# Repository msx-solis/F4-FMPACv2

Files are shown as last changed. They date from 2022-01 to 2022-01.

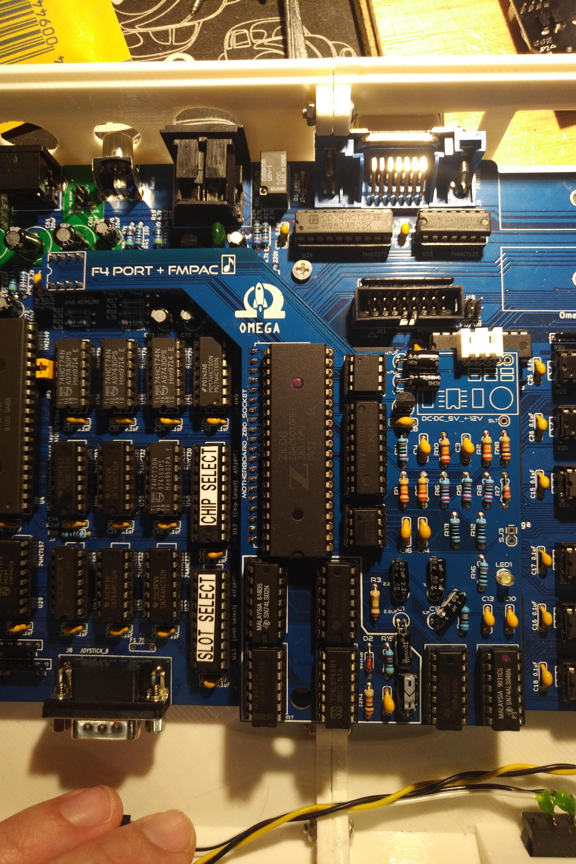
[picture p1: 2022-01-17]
pictures/IMG_20210918_0122434.jpg

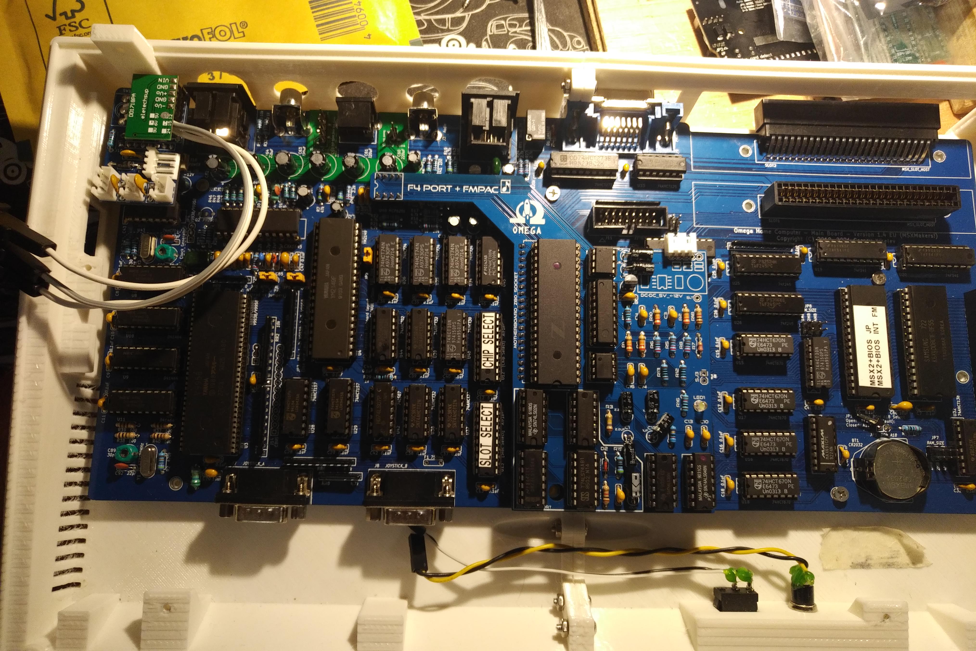
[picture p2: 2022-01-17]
pictures/IMG_20210918_0122565.jpg

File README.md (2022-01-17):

# F4-FMPACv2
Placa de circuito impreso diseñada a partir del proyecto F4-FMPAC del grupo RSBC.
Este circuito permite mejorar las capacidades musicales de los ordenadores MSX, es compatible con los estándares FMPAC y msxmusic.
La versión 2 está especificamente diseñada para adaptarse a las dimensiones del OMEGA HOME COMPUTER, y a diferencia de la versión anterior su diseño evita tener que soldar componentes de superficie (SMD) para facilitar la construcción por parte de los más novatos.
El circuito dispone de dos tiras de pines en la parte inferior para ser insertadas en el zocalo del procesador z80, que debe ser extraido de la placa base original e instalado en el zócalo destinado a tal efecto en esta placa.
Además requiere de ser alimentado a +12v y -12v porque de lo contrario el OMEGA no iniciará adecuadamente.
La alimentación puede ser suministrada mediante un módulo eletechsup DD1718PA de +12/-12v, instalando este en el zócalo previsto para tal proposito, o bien proporcionando dichos voltages en los pines 3-5 de dicho zócalo.
También requiere la reprogramación de la ROM del sistema para incorporar una extensión del BIOS que dé soporte a este circuito, de lo contrario los programas que soportan la extensión seguirán omitiendo el módulo y utilizando el sistema FM principal.
A diferencia de la versión anterior este PCB no incorpora zócalo para memoria ROM ni señales a tomar de un slot de cartucho.
Como instrucciones de montaje se pueden seguir las publicadas para la versión anterior en:
https://msxmakers.design.blog/proyectos/f4-fmpac/

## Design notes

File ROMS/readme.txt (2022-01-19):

Esta carpeta contiene un fichero binario para grabar las ROM del sistema OMEGA con 2 paginas distintas.
Una de las páginas tiene el sistema configurado con la ROM MSX2+ original y la segunda incluye varias modificaciones:
- Configuración regional internacional.
- Símbolo de contrabarra en lugar del yen.
- Soporte para fmpac (en caso de no estar instalado algunos juegos pierden el sonido).
Con este sistema, conectando un interruptor a JP1 de la placa base se puede conmutar entre ambas opciones, la configuración
regional es inmediata, el soporte de FMPAC requiere reiniciar.

Se incluye el script de creación y los ficheros necesarios para modificarlo al gusto.

Nota: Pendiente de revisar si los ficheros que subí están mal, añado un script y ROM probados por MerlinKV.

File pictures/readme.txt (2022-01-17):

Algunas imágenes de la instalación del módulo.
Una de ellas con el módulo eletechsup instalado y otras con un conector JST en su lugar.
Como se muestra es posible encajar el módulo dentro de la carcasa del omega "SVI728" para impresión 3D siempre y cuando se recorte
la barra de soporte del teclado y aunque no lo muestran así las imágenes, es recomendable que los circuitos integrados de la primera 
fila estén soldados directamente en la placa o con zócalos de bajo perfil.

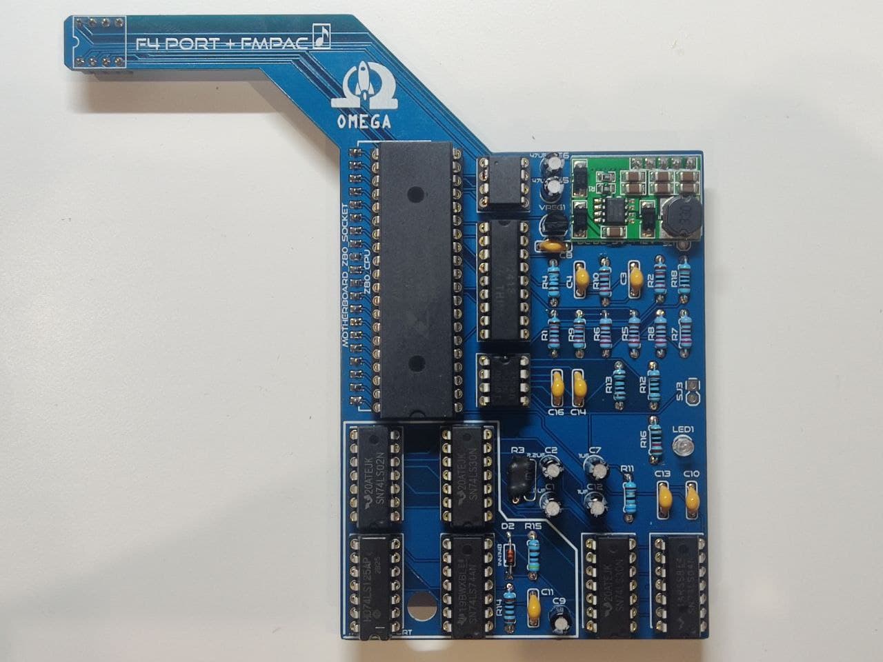
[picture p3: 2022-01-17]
pictures/f4fmpac_v2.jpg

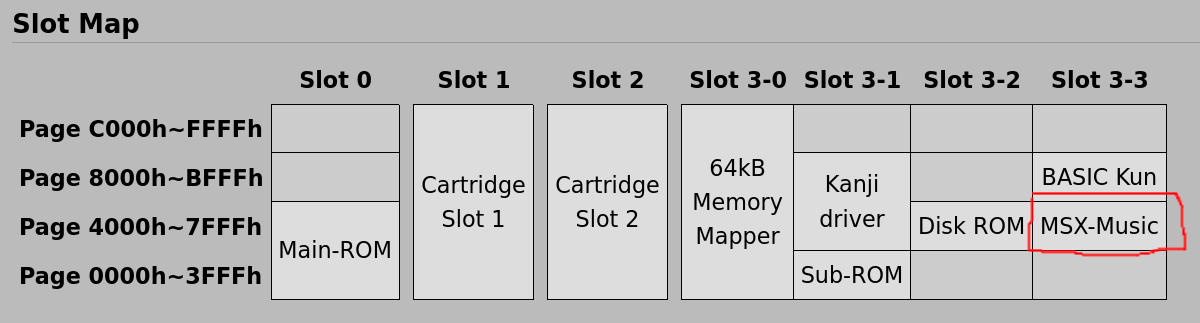
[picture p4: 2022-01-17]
pictures/slotmap.jpg

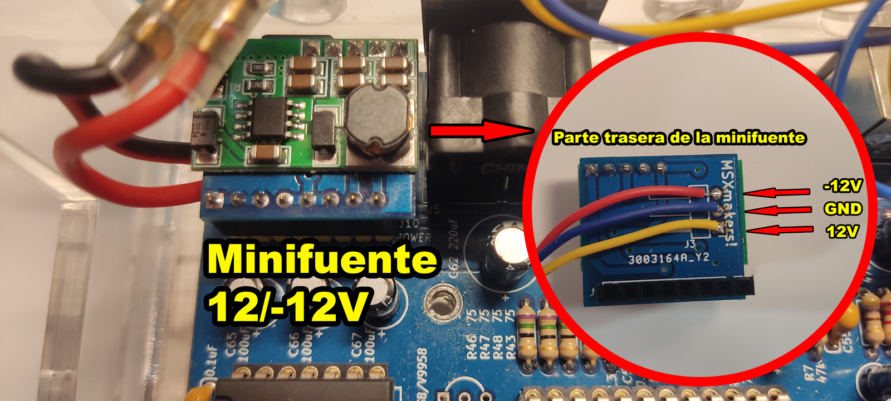
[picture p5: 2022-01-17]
pictures/imagen16.png

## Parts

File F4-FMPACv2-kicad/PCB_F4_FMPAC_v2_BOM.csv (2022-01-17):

Reference | Quantity | Value | Footprint | Datasheet
C1 C2 | 2 | 2.2uF25v | Capacitor_THT:CP_Radial_D5.0mm_P2.50mm
C8 C10 C11 C13 | 4 | 100nF | Capacitor_THT:C_Disc_D4.3mm_W1.9mm_P5.00mm
C14 C16 | 2 | 1nF | Capacitor_THT:C_Disc_D4.3mm_W1.9mm_P5.00mm
C3 C4 | 2 | 22pF | Capacitor_THT:C_Disc_D4.3mm_W1.9mm_P5.00mm
C5 C6 | 2 | 47uF 16v | Capacitor_THT:CP_Radial_D7.5mm_P2.50mm
C7 C12 | 2 | 1uF 25v | Capacitor_THT:CP_Radial_D5.0mm_P2.50mm
C9 | 1 | 10uF 16V | Capacitor_THT:CP_Radial_D5.0mm_P2.50mm
CN1 | 1 | DIP40 MB CONN | Package_DIP:DIP-40_W15.24mm
D2 | 1 | 1N4148 | Diode_THT:D_DO-35_SOD27_P7.62mm_Horizontal | https://assets.nexperia.com/documents/data-sheet/1N4148_1N4448.pdf
IC1 | 1 | YM2413 | Package_DIP:DIP-18_W7.62mm
IC2 IC6 | 2 | 74LS30D | Package_DIP:DIP-14_W7.62mm
IC3 | 1 | 74LS04D | Package_DIP:DIP-14_W7.62mm
IC4 | 1 | LM4558N | Package_DIP:DIP-8_W7.62mm
IC5 | 1 | Z80 | Package_DIP:DIP-40_W15.24mm
IC7 | 1 | 74LS02D | Package_DIP:DIP-14_W7.62mm
IC8 | 1 | 74LS74D | Package_DIP:DIP-14_W7.62mm
IC9 | 1 | 74LS125D | Package_DIP:DIP-14_W7.62mm
JP1 | 1 | Conn_01x05 | Connector_PinHeader_2.54mm:PinHeader_1x05_P2.54mm_Vertical | ~
LED1 | 1 | LED 3mm | LED_THT:LED_D3.0mm | ~
R11 | 1 | 68 | Resistor_THT:R_Axial_DIN0207_L6.3mm_D2.5mm_P7.62mm_Horizontal
R12 R13 | 2 | 100 | Resistor_THT:R_Axial_DIN0207_L6.3mm_D2.5mm_P7.62mm_Horizontal
R14 | 1 | 1k | Resistor_THT:R_Axial_DIN0207_L6.3mm_D2.5mm_P7.62mm_Horizontal
R15 | 1 | 4.7k | Resistor_THT:R_Axial_DIN0207_L6.3mm_D2.5mm_P7.62mm_Horizontal
R16 | 1 | 470 | Resistor_THT:R_Axial_DIN0207_L6.3mm_D2.5mm_P7.62mm_Horizontal
R1 R2 R9 R10 | 4 | 22k | Resistor_THT:R_Axial_DIN0207_L6.3mm_D2.5mm_P7.62mm_Horizontal
R3 | 1 | 170k | Resistor_THT:R_Axial_DIN0207_L6.3mm_D2.5mm_P7.62mm_Horizontal
R4 R5 R6 R7 R8 | 5 | 2.2k | Resistor_THT:R_Axial_DIN0207_L6.3mm_D2.5mm_P7.62mm_Horizontal
SJ3 | 1 | SJ | Connector_PinHeader_2.54mm:PinHeader_1x02_P2.54mm_Vertical
U2 | 1 | SOCKET DIP | Package_DIP:DIP-8_W7.62mm | http://ww1.microchip.com/downloads/en/DeviceDoc/21314g.pdf
U48 | 1 | MCP6182 | Package_DIP:DIP-8_W7.62mm | http://ww1.microchip.com/downloads/en/DeviceDoc/21314g.pdf
VREG1 | 1 | 78L | Package_TO_SOT_THT:TO-92L_Wide

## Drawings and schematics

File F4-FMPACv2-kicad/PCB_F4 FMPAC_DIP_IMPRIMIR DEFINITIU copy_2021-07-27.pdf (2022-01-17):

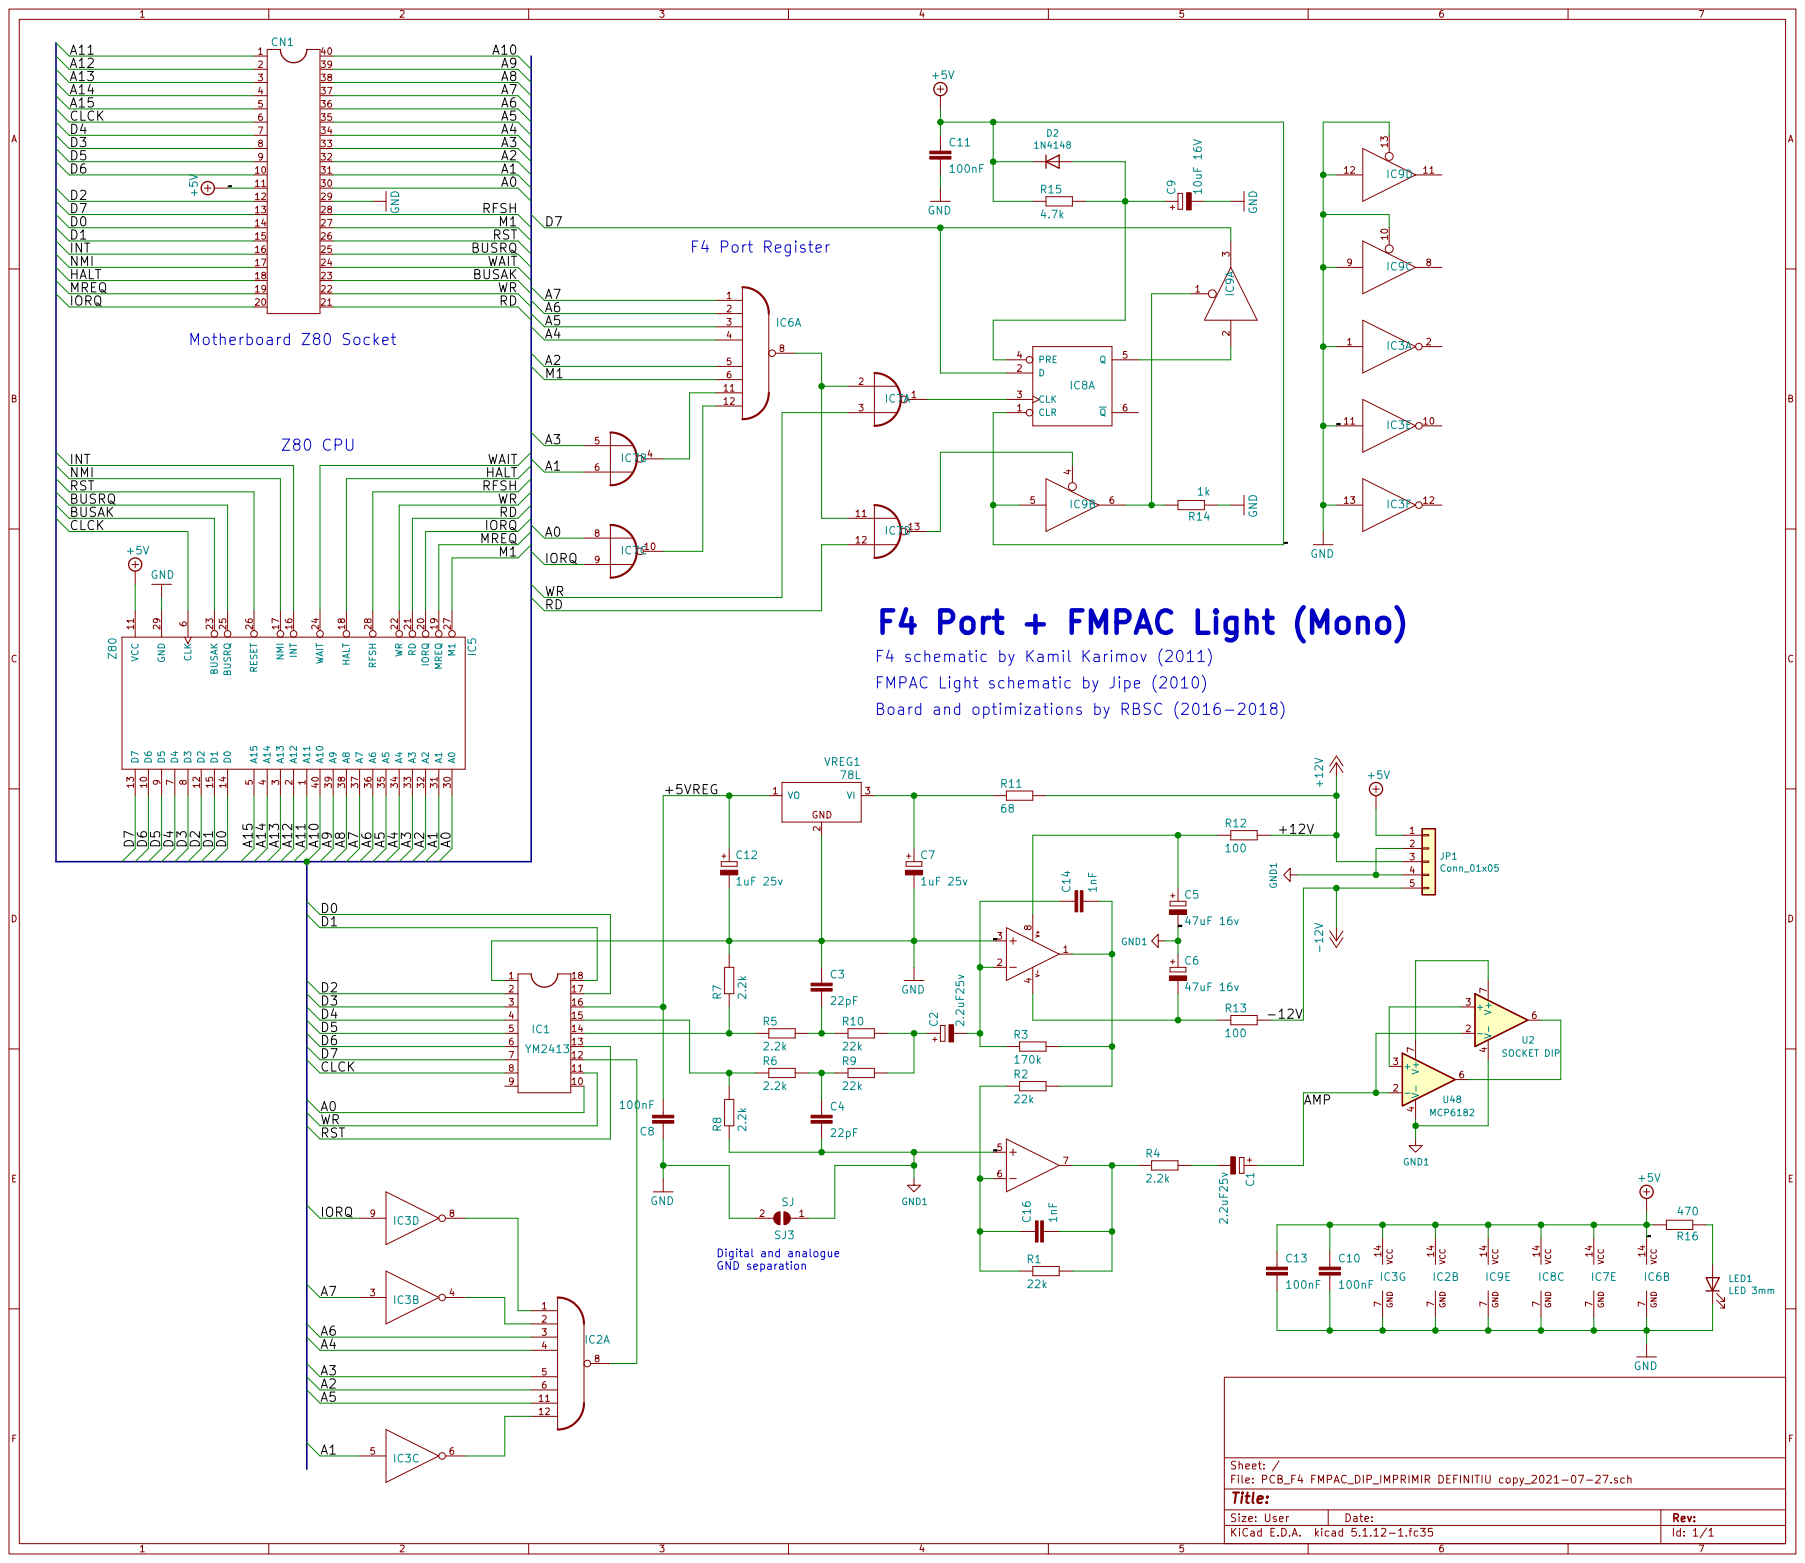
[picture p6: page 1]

1 D6 10 VCC 11 D2 12 D7 13 D0 14 D1 15 INT 16 NMI 17 HALT 18 MREQ 19 A12

2 IORQ 20 RD 21 WR 22 BUSAK 23 WAIT 24 BUSRQ 25 RESET 26 M1 27 RFSH 28 GND 29 A13

F4 schematic by Kamil Karimov (2011)
FMPAC Light schematic by Jipe (2010)
Board and optimizations by RBSC (2016-2018)

File: PCB_F4 FMPAC_DIP_IMPRIMIR DEFINITIU copy_2021-07-27.sch Sheet: /

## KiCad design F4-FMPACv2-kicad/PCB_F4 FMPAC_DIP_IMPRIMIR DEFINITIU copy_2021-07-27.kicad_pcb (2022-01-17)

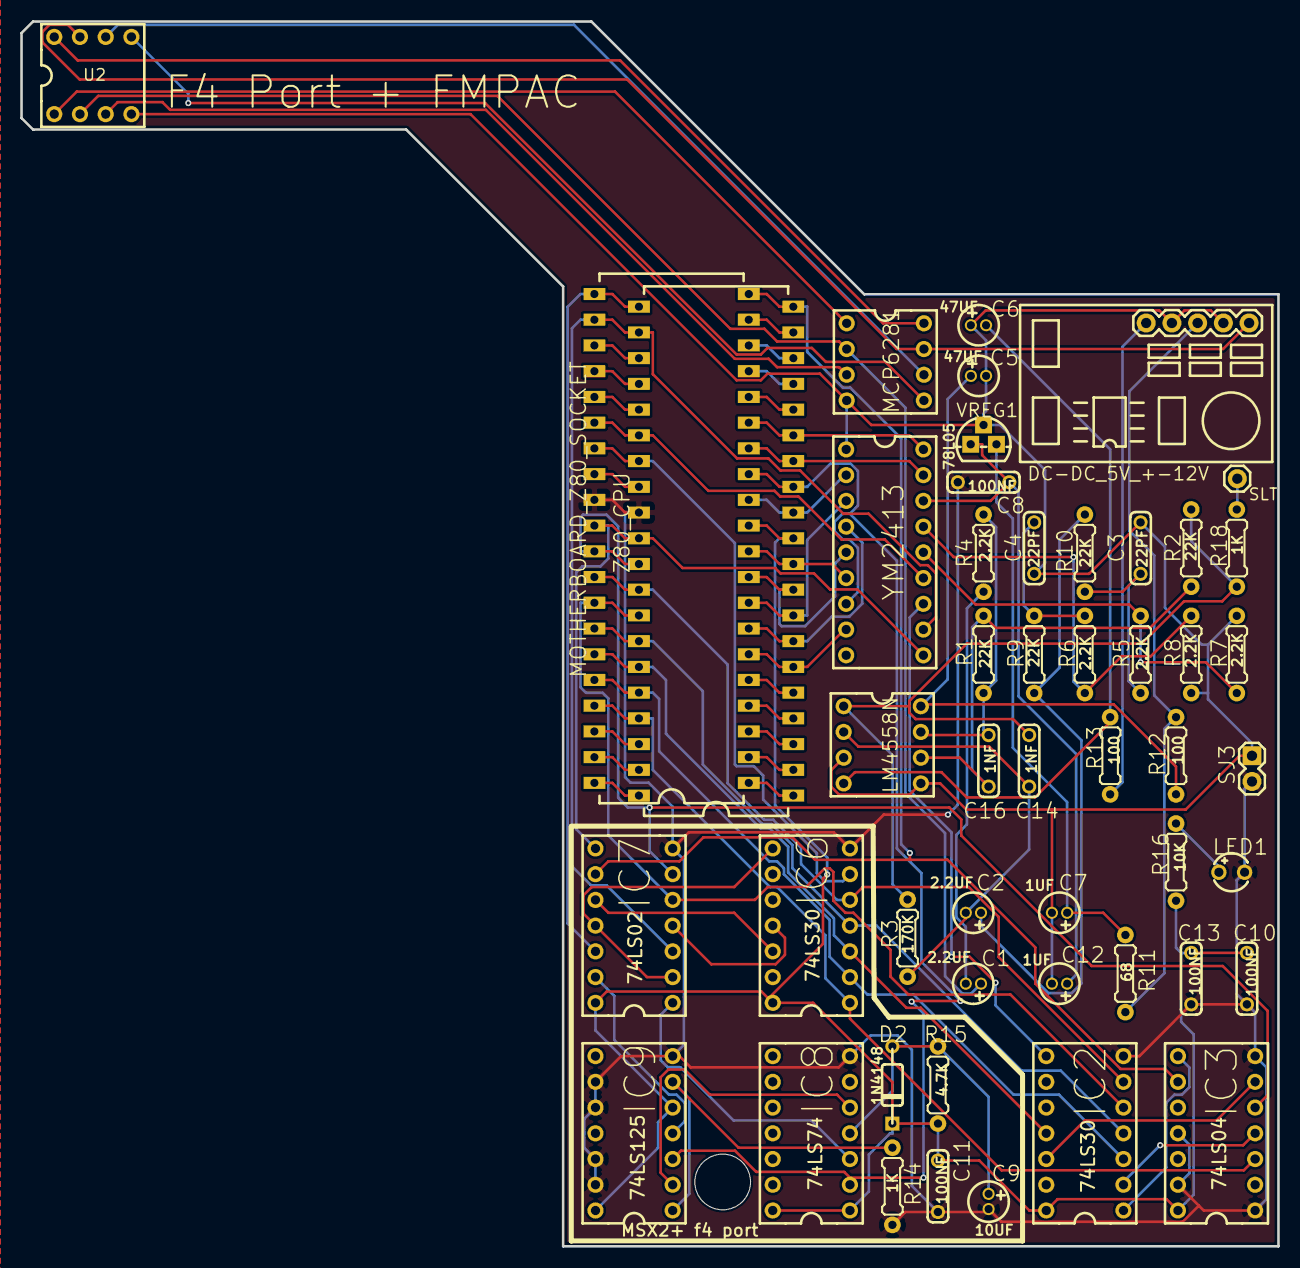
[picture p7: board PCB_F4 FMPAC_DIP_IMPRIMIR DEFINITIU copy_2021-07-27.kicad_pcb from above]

Board: 2 copper layers, 124.1 x 120.9 mm, 50 parts (0 on the bottom side), 78 nets.

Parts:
C1, C2: 2.2uF25v; CAPACITOR ELECTROLITYC 10UF
C3, C4: 22pF; CAPACITOR OMEGA 0.1UF
C5, C6: 47uF 16v; CAPACITOR ELECTROLITYC 10UF
C7, C12: 1uF 25v; CAPACITOR ELECTROLITYC 10UF
C8, C10, C11, C13: 100nF; CAPACITOR OMEGA 0.1UF
C9: 10uF 16V; CAPACITOR ELECTROLITYC 10UF
C14, C16: 1nF; CAPACITOR OMEGA 0.1UF
D2: 1N4148WSF-7; DIODE_ZENER
DC-DC_5V_+-12V: dc-dc 5v +-12v; DC-DC 5V +-12V
IC2, IC6: 74LS30D; DIP-14
IC3: 74LS04D; DIP-14
IC7: 74LS02D; DIP-14
IC8: 74LS74D; DIP-14
IC9: 74LS125D; DIP-14
LED1: LED 3MM; LED-TH_BD3.8-P2.54-FD
LM4558N: LM4558N; DIP-8
MCP6281: MCP6281; DIP-8
MOTHERBOARD_Z80_SOCKET: DIP40 MB CONN; DIL40
R1, R2, R9, R10: 22k; RESISTOR 1_4W
R3: 170k; RESISTOR 1_4W
R4, R15: 4.7k; RESISTOR 1_4W
R5, R6, R7, R8: 2.2k; RESISTOR 1_4W
R11: 68; RESISTOR 1_4W
R12, R13: 100; RESISTOR 1_4W
R14, R18: 1k; RESISTOR 1_4W
R16: Resistor; RESISTOR 1_4W
SJ3: SJ; 2PIN_CONNECTOR PIN1 0X,0Y
SLT: SLT; 1PIN_CONNECTOR PIN1 0X,0Y
U2: SOCKET DIP; DIP-8
VREG1: 7805L; TO92
YM2413: YM2413; DIP-18
Z80_CPU: Z80; DIL40

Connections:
+5V: C10.1, C11.1, C13.1, D2.1, IC2.14, IC3.14, IC6.14, IC7.14, IC8.1, IC8.14, IC9.5, IC9.14, MOTHERBOARD_Z80_SOCKET.11, R15.1, R16.2, Z80_CPU.11
+5VREG: C8.2, C12.+, VREG1.1, YM2413.16
+12V: DC-DC_5V_+-12V.3, R11.2, R12.2
-12V: DC-DC_5V_+-12V.5, R13.2
A0: IC7.8, MOTHERBOARD_Z80_SOCKET.30, YM2413.10, Z80_CPU.30
A1: IC3.5, IC7.6, MOTHERBOARD_Z80_SOCKET.31, Z80_CPU.31
A2: IC2.6, IC6.5, MOTHERBOARD_Z80_SOCKET.32, Z80_CPU.32
A3: IC2.5, IC7.5, MOTHERBOARD_Z80_SOCKET.33, Z80_CPU.33
A4: IC2.4, IC6.4, MOTHERBOARD_Z80_SOCKET.34, Z80_CPU.34
A5: IC2.11, IC6.3, MOTHERBOARD_Z80_SOCKET.35, Z80_CPU.35
A6: IC2.3, IC6.2, MOTHERBOARD_Z80_SOCKET.36, Z80_CPU.36
A7: IC3.3, IC6.1, MOTHERBOARD_Z80_SOCKET.37, Z80_CPU.37
A8: MOTHERBOARD_Z80_SOCKET.38, Z80_CPU.38
A9: MOTHERBOARD_Z80_SOCKET.39, Z80_CPU.39
A10: MOTHERBOARD_Z80_SOCKET.40, Z80_CPU.40
A11: MOTHERBOARD_Z80_SOCKET.1, Z80_CPU.1
A12: MOTHERBOARD_Z80_SOCKET.2, Z80_CPU.2
A13: MOTHERBOARD_Z80_SOCKET.3, Z80_CPU.3
A14: MOTHERBOARD_Z80_SOCKET.4, Z80_CPU.4
A15: MOTHERBOARD_Z80_SOCKET.5, Z80_CPU.5
AMP: C1.+, MCP6281.2, U2.2
BUSAK: MOTHERBOARD_Z80_SOCKET.23, Z80_CPU.23
BUSRQ: MOTHERBOARD_Z80_SOCKET.25, Z80_CPU.25
C1_-: C1.-, R4.2
C2_+: C2.+, R9.2, R10.2
C2_-: C2.-, C14.1, LM4558N.2, R3.1
C3_2: C3.2, R5.2, R10.1
C4_1: C4.1, R6.2, R9.1
C5_+: C5.+, LM4558N.8, R12.1
C6_-: C6.-, LM4558N.4, R13.1
C7_+: C7.+, R11.1, VREG1.3
CLCK: MOTHERBOARD_Z80_SOCKET.6, YM2413.8, Z80_CPU.6
D0: MOTHERBOARD_Z80_SOCKET.14, YM2413.17, Z80_CPU.14
D1: MOTHERBOARD_Z80_SOCKET.15, YM2413.18, Z80_CPU.15
D2: MOTHERBOARD_Z80_SOCKET.12, YM2413.2, Z80_CPU.12
D3: MOTHERBOARD_Z80_SOCKET.8, YM2413.3, Z80_CPU.8
D4: MOTHERBOARD_Z80_SOCKET.7, YM2413.4, Z80_CPU.7
D5: MOTHERBOARD_Z80_SOCKET.9, YM2413.5, Z80_CPU.9
D6: MOTHERBOARD_Z80_SOCKET.10, YM2413.6, Z80_CPU.10
D7: IC8.2, IC9.3, MOTHERBOARD_Z80_SOCKET.13, YM2413.7, Z80_CPU.13
GND: C8.1, C9.-, C10.2, C11.2, C13.2, IC2.7, IC3.1, IC3.7, IC3.11, IC3.13, IC6.7, IC7.7, IC8.7, IC9.7, IC9.9, IC9.10, IC9.12, IC9.13, LED1.2, MOTHERBOARD_Z80_SOCKET.29, R14.1, SJ3.2, Z80_CPU.29
GND1: C3.1, C4.2, C5.-, C6.+, C7.-, C12.-, DC-DC_5V_+-12V.2, DC-DC_5V_+-12V.4, LM4558N.3, LM4558N.5, MCP6281.4, R7.2, R8.1, SJ3.1, U2.4, VREG1.2, YM2413.1
HALT: MOTHERBOARD_Z80_SOCKET.18, Z80_CPU.18
IC1_12: IC2.8, YM2413.12
IC1_14: R5.1, R7.1, YM2413.14
IC1_15: R6.1, R8.2, YM2413.15
IC2_1: IC2.1, IC3.8
IC2_2: IC2.2, IC3.4
IC2_12: IC2.12, IC3.6
IC4_1: C14.2, LM4558N.1, R2.2, R3.2, R18.1
IC4_6: C16.1, LM4558N.6, R1.1, R2.1
IC4_7: C16.2, LM4558N.7, R1.2, R4.1
IC6_8: IC6.8, IC7.2, IC7.11
IC6_11: IC6.11, IC7.4
IC6_12: IC6.12, IC7.10
IC8_3: IC7.1, IC8.3
IC8_4: C9.+, D2.2, IC8.4, R15.2
IC8_5: IC8.5, IC9.2
IC9_4: IC7.13, IC9.4
INT: MOTHERBOARD_Z80_SOCKET.16, Z80_CPU.16
IORQ: IC3.9, IC7.9, MOTHERBOARD_Z80_SOCKET.20, Z80_CPU.20
LED1_1: LED1.1, R16.1
M1: IC6.6, MOTHERBOARD_Z80_SOCKET.27, Z80_CPU.27
MREQ: MOTHERBOARD_Z80_SOCKET.19, Z80_CPU.19
NMI: MOTHERBOARD_Z80_SOCKET.17, Z80_CPU.17
R14_2: IC9.1, IC9.6, R14.2
RD: IC7.12, MOTHERBOARD_Z80_SOCKET.21, Z80_CPU.21
RFSH: MOTHERBOARD_Z80_SOCKET.28, Z80_CPU.28
RST: MOTHERBOARD_Z80_SOCKET.26, YM2413.13, Z80_CPU.26
SLT: R18.2, SLT.1
U48B_1: MCP6281.1, U2.1
U48B_3: MCP6281.3, U2.3
U48B_5: MCP6281.5, U2.5
U48B_6: MCP6281.6, U2.6
U48B_7: DC-DC_5V_+-12V.1, MCP6281.7, U2.7
U48B_8: MCP6281.8, U2.8
WAIT: MOTHERBOARD_Z80_SOCKET.24, Z80_CPU.24
WR: IC7.3, MOTHERBOARD_Z80_SOCKET.22, YM2413.11, Z80_CPU.22

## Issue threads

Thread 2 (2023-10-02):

Files & Gerber are version 1.2, not 2.0

Sch-LikA, 2023-10-02:
Hello !

First thanks a lot for the work, amazing stuff. I recently got the gerbers made at JLC, and discovered that the ones in the repo are version 1.2, and I see references to a version 2.0 on the msxmakers blog.

Could you update the repo, and since I have the 1.2 version, is there any important difference between the 2 versions ?

Thanks !!

msx-solis, 2023-10-05:
Hi,
The Gerber files at the github are the right one for this board.
This board is based on the previous RBSC group FM board and that was v 1.4 for them, so that we upgraded its board number to indicate this one is later.
We have an upgrade to this board, called FM+turbo HAT but we would like to make it public when we would develop detailed documentation. If you want this one please send us an email.
Have a nice day!
